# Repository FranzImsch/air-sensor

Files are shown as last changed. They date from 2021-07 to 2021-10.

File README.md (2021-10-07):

# Air Sensor V1.0
A small solar powered ZigBee compatible sensor with energy harvesting for temperature, humidity and VOCs.  
Features nRF52840, AEM10941, SHT40 and SGP40.

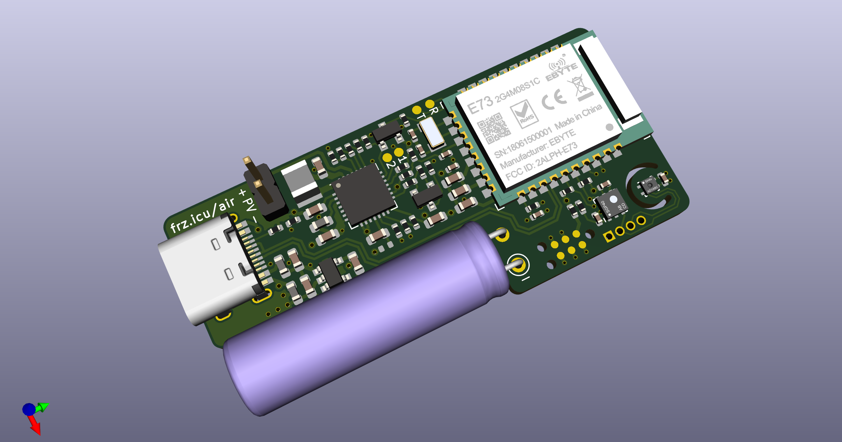
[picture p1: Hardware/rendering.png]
Rendering


## Known Flaws
* Due to the extremely high resistor values of the voltage dividers and their corresponding errors, the set voltage limits are very inaccurate. 
* The overall performance is not completely satisfying, especially indoors pretty much no energy is harvested. (Maybe a different chip like TI's [BQ25570](https://www.ti.com/lit/ds/symlink/bq25570.pdf) could perform better.) The Sensirion sensors perform excellently.

## Software
The proper software (that uses ZigBee) is to be developed. The existing software is a very rudimentary Arduino example to test the sensors. It draws way too much power to be used.

## BOM
The interactive BOM can be found [here](https://franz.science/airsensor-v1.0-ibom/).  

## Reference
e-peas Configuration tool (for the resistors) in the resources section: [Product page](https://e-peas.com/product/aem10941/).

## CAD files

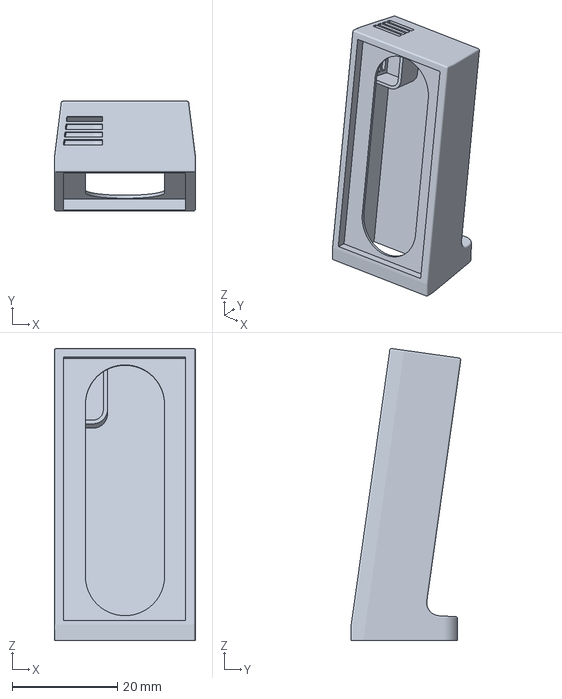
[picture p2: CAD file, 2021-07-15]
Hardware/UMS5_Case.3mf
26.8 x 20.8 x 55.4 mm

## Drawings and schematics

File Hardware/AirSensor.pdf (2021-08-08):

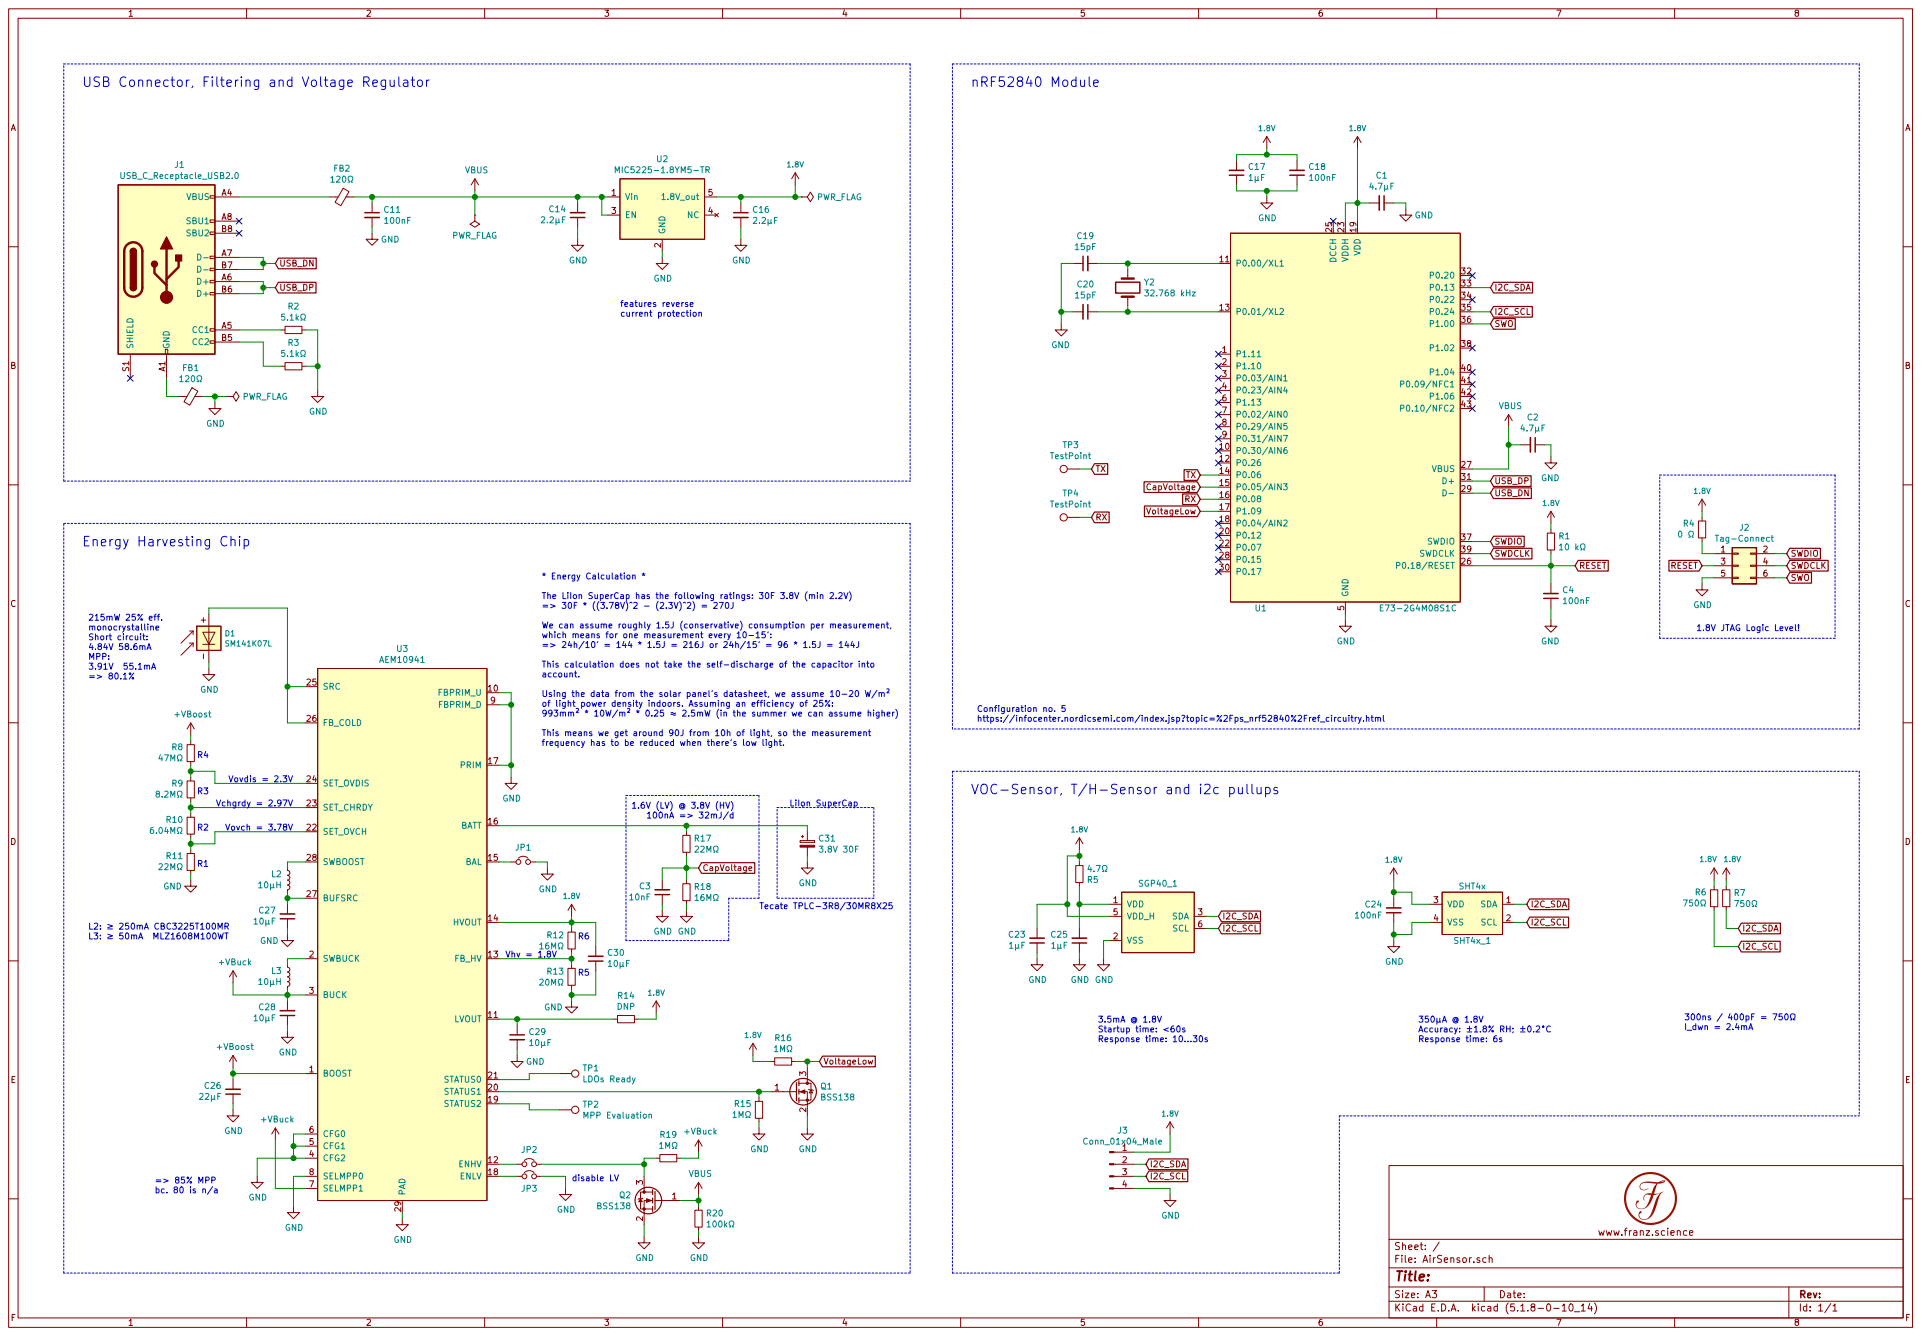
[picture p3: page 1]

The LiIon SuperCap has the following ratings: 30F 3.8V (min 2.2V)

215mW 25% eff. monocrystalline Short circuit: 4.84V 58.6mA MPP: 3.91V 55.1mA

We can assume roughly 1.5J (conservative) consumption per measurement,
which means for one measurement every 10-15: => 24h/10 = 144 * 1.5J = 216J or 24h/15 = 96 * 1.5J = 144J This calculation does not take the self-discharge of the capacitor into

account. Using the data from the solar panels datasheet, we assume 10-20 W/m²

LDOs Ready TP2 MPP Evaluation GND

of light power density indoors. Assuming an efficiency of 25%:
993mm² * 10W/m² * 0.25 2.5mW (in the summer we can assume higher)

https://infocenter.nordicsemi.com/index.jsp?topic=%2Fps_nrf52840%2Fref_circuitry.html

This means we get around 90J from 10h of light, so the measurement

frequency has to be reduced when theres low light. Vovdis = 2.3V

VOC-Sensor, T/H-Sensor and i2c pullups

LiIon SuperCap Tecate TPLC-3R8/30MR8X25

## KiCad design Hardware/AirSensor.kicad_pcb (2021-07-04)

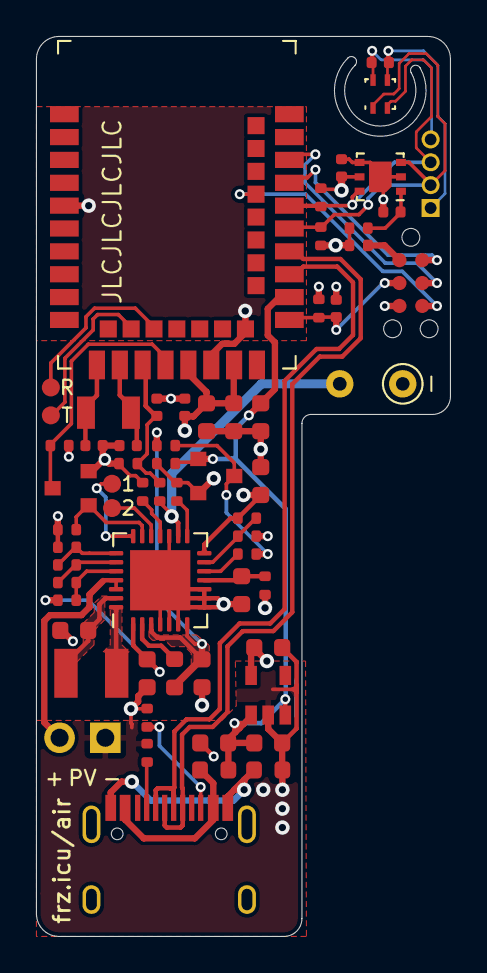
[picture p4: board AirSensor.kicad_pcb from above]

Board: 4 copper layers, 23.0 x 50.0 mm, 63 parts (0 on the bottom side), 42 nets.

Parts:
C1, C2: 4.7µF; C_0603_1608Metric
C3: 10nF; C_0402_1005Metric
C4, C18, C24: 100nF; C_0402_1005Metric
C11: 100nF; C_0603_1608Metric
C14, C16: 2.2µF; C_0603_1608Metric
C17: 1µF; C_0603_1608Metric
C19, C20: 15pF; C_0402_1005Metric
C23, C25: 1µF; C_0402_1005Metric
C26: 22µF; C_0603_1608Metric
C27, C28, C29, C30: 10µF; C_0603_1608Metric
C31: 3.8V 30F; TPLC-3R8_30MR8X25
D1: SM141K07L; PinHeader_1x02_P2.54mm_Vertical
FB1, FB2: 120Ω; L_0603_1608Metric
J1: USB_C_Receptacle_USB2.0; USB_C_Receptacle_HRO_TYPE-C-31-M-12
J2: Tag-Connect; Tag-Connect_TC2030-IDC-NL_2x03_P1.27mm_Vertical
J3: Conn_01x04_Male; PinHeader_1x04_P1.27mm_Vertical
JP1, JP2, JP3: Jumper_NC_Small; R_0402_1005Metric
L2: 10µH; INDC3225X270N
L3: 10µH; L_0603_1608Metric
Q1, Q2: BSS138; SOT-23
R1: 10 kΩ; R_0402_1005Metric
R2, R3: 5.1kΩ; R_0402_1005Metric
R4: 0 Ω; R_0402_1005Metric
R5: 4.7Ω; R_0402_1005Metric
R6, R7: 750Ω; R_0402_1005Metric
R8: 47MΩ; R_0402_1005Metric
R9: 8.2MΩ; R_0402_1005Metric
R10: 6.04MΩ; R_0402_1005Metric
R11, R17: 22MΩ; R_0402_1005Metric
R12, R18: 16MΩ; R_0402_1005Metric
R13: 20MΩ; R_0402_1005Metric
R14: DNP; R_0402_1005Metric
R15, R16, R19: 1MΩ; R_0402_1005Metric
R20: 100kΩ; R_0402_1005Metric
SGP40_1: SGP40
SHT4x_1: SHT4x; Sensirion_SHT4x
TP1: LDOs Ready; TestPoint_Pad_D1.0mm
TP2: MPP Evaluation; TestPoint_Pad_D1.0mm
TP3, TP4: TestPoint; TestPoint_Pad_D1.0mm
U1: E73-2G4M08S1C
U2: MIC5225-1.8YM5-TR; SOT-23-5
U3: AEM10941; QFN-28-1EP_5x5mm_P0.5mm_EP3.35x3.35mm
Y2: 32.768 kHz; Crystal_SMD_3215-2Pin_3.2x1.5mm

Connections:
1.8V: C1.2, C16.1, C17.2, C18.2, C23.2, C24.2, C30.2, J3.1, R1.1, R4.2, R5.1, R6.2, R7.1, R12.1, R14.1, R16.2, SGP40_1.5, SHT4x_1.3, U1.19, U1.23, U2.5, U3.14
+VBoost: C26.2, R8.2, U3.1
+VBuck: C28.2, L3.1, R19.1, U3.3, U3.7
CapVoltage: C3.2, R17.2, R18.1, U1.15
GND: C1.1, C2.1, C3.1, C4.1, C11.2, C14.1, C16.2, C17.1, C18.1, C19.1, C20.2, C23.1, C24.1, C25.1, C26.1, C27.1, C28.1, C29.2, C30.1, C31.-, D1.1, FB1.1, J2.5, J3.4, JP1.2, JP3.2, Q1.2, Q2.2, R2.1, R3.1, R11.1, R13.2, R15.1, R18.2, R20.2, SGP40_1.2, SGP40_1.4, SGP40_1.PAD, SHT4x_1.4, U1.5, U1.21, U1.24, U2.2, U3.4, U3.5, U3.6, U3.8, U3.9, U3.10, U3.17, U3.29
I2C_SCL: J3.3, R6.1, SGP40_1.6, SHT4x_1.2, U1.35
I2C_SDA: J3.2, R7.2, SGP40_1.3, SHT4x_1.1, U1.33
unnamed: C19.2, U1.11, Y2.1
unnamed: C20.1, U1.13, Y2.2
unnamed: C25.2, R5.2, SGP40_1.1
unnamed: C27.2, L2.1, U3.27
unnamed: C29.1, R14.2, U3.11
unnamed: C31.+, R17.1, U3.16
unnamed: D1.2, U3.25, U3.26
unnamed: FB1.2, J1.A1, J1.A12, J1.B1, J1.B12
unnamed: FB2.2, J1.A4, J1.A9, J1.B4, J1.B9
unnamed: J1.A5, R2.2
unnamed: J1.B5, R3.2
unnamed: J2.1, R4.1
unnamed: JP1.1, U3.15
unnamed: JP2.1, U3.12
unnamed: JP2.2, Q2.3, R19.2
unnamed: JP3.1, U3.18
unnamed: L2.2, U3.28
unnamed: L3.2, U3.2
unnamed: Q1.1, R15.2, U3.20
unnamed: R8.1, R9.2, U3.24
unnamed: R10.1, R11.2, U3.22
unnamed: R9.1, R10.2, U3.23
unnamed: R12.2, R13.1, U3.13
unnamed: TP1.1, U3.21
unnamed: TP2.1, U3.19
RESET: C4.2, J2.3, R1.2, U1.26
RX: TP4.1, U1.16
SWDCLK: J2.4, U1.39
SWDIO: J2.2, U1.37
SWO: J2.6, U1.36
TX: TP3.1, U1.14
USB_DN: J1.A7, J1.B7, U1.29
USB_DP: J1.A6, J1.B6, U1.31
VBUS: C2.2, C11.1, C14.2, FB2.1, Q2.1, R20.1, U1.27, U2.1, U2.3
VoltageLow: Q1.3, R16.1, U1.17

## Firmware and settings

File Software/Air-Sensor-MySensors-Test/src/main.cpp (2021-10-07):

#include <Arduino.h>
#include "Adafruit_SHT4x.h"
#include "Adafruit_SGP40.h"

/////// MYSENORS SETTINGS ///////
#define MY_DEBUG
#define MY_RADIO_NRF5_ESB
#define CHILD_ID_TEMP 1
#define CHILD_ID_HUM 2
#define CHILD_ID_IAQ 3
#define SN "air-quality"
#define SV "1.0"
// #define MY_NODE_ID 193

/////// PIN DEFINITIONS ///////
#define CAP_VOLTAGE 16 // P0.05 => D16
#define VOLT_LOW 38    // P1.09 => D38

/////// VOLTAGE MEASUREMENT ///////
#define ADC_FACTOR (0.73242188F)  // 3V / 4096
#define RESISTOR_DIVIDER (678.0F) // this factor has to be determined for every individual device

#include <MySensors.h>

/////// INTERNALS ///////
MyMessage temp_msg(CHILD_ID_TEMP, V_TEMP);
MyMessage hum_msg(CHILD_ID_HUM, V_HUM);
MyMessage iaq_msg(CHILD_ID_IAQ, V_LEVEL);
bool sentInitialValue = false;

bool powerDown = false;

long lastsent = 0;

float lastTemp, lastHum, lastIAQ;

Adafruit_SGP40 sgp;
Adafruit_SHT4x sht4 = Adafruit_SHT4x();

uint32_t i;

void LOW_VOLTAGE_ISR()
{
  powerDown = true;
  Serial.println("----- POWER DOWN!!! -----");
}

void presentation()
{
  sendSketchInfo(SN, SV);
  present(CHILD_ID_TEMP, S_TEMP);
  present(CHILD_ID_HUM, S_HUM);
  present(CHILD_ID_IAQ, S_AIR_QUALITY);
}

void setup()
{

  attachInterrupt(VOLT_LOW, LOW_VOLTAGE_ISR, FALLING);

  // put your setup code here, to run once:
  if (!sht4.begin())
  {
    Serial.println("Couldn't find SHT4x");
    while (1)
      delay(1);
  }
  Serial.println("Found SHT4x sensor");
  Serial.print("Serial number 0x");
  Serial.println(sht4.readSerial(), HEX);
  sht4.setPrecision(SHT4X_MED_PRECISION);
  sht4.setHeater(SHT4X_NO_HEATER);

  if (!sgp.begin())
  {
    Serial.println("SGP40 sensor not found :(");
    while (1)
      ;
  }
  Serial.print("Found SHT3x + SGP40 serial #");
  Serial.print(sgp.serialnumber[0], HEX);
  Serial.print(sgp.serialnumber[1], HEX);
  Serial.println(sgp.serialnumber[2], HEX);
}

void loop()
{
  // For Home Assistant, the first message has to be sent from the loop.
  sensors_event_t humidity, temp;
  sht4.getEvent(&humidity, &temp); // populate temp and humidity objects with fresh data

  if (!sentInitialValue)
  {
    send(temp_msg.set(22, 3)); // send dummy value
    send(hum_msg.set(50, 3));  // send dummy value
    send(iaq_msg.set(100, 0)); // send dummy value
    sendBatteryLevel(50);
    wait(2000);
    sentInitialValue = true;

    for (int n = 0; n <= 230; n++)
    {
      float t = temp.temperature;
      float h = humidity.relative_humidity;
      uint32_t voc_index;
      voc_index = sgp.measureVocIndex(t, h);
      Serial.println(voc_index);
      delay(50);
    }
    Serial.println("finished setup");
  }

  if (!powerDown)
  {
    sensors_event_t humidity, temp;
    sht4.getEvent(&humidity, &temp); // populate temp and humidity objects with fresh data

    float t = temp.temperature;
    float h = humidity.relative_humidity;
    Serial.print("T: ");
    Serial.println(t);
    Serial.print("H: ");
    Serial.println(h);

    uint32_t voc_index;

    voc_index = sgp.measureVocIndex(t, h);
    Serial.print("Voc Index: ");
    Serial.println(voc_index);

    long now = millis();

    if (now >= lastsent + 30000)
    {
      lastsent = now;
      if (t > (lastTemp + 0.5) || t < (lastTemp - 0.5))
      {
        send(temp_msg.set(t, 3));
        lastTemp = t;
      }
      if (h > (lastHum + 3) || h < (lastHum - 3))
      {
        send(hum_msg.set(h, 3));
        lastHum = h;
      }
      if (voc_index > lastIAQ + 2 || voc_index < lastIAQ - 2)
      {
        send(iaq_msg.set(voc_index, 0));
        lastIAQ = voc_index;
      }
    }
  }
  sleep(900000); // 15 Minutes
}

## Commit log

2021-07-04 initialising repo
    [AirSensor.kicad_pcb, AirSensor.sch]
2021-07-15 fixed ibom and added 3d print file
    [AirSensor.kicad_pcb, AirSensor.sch, UMS5_Case.3mf]
2021-08-08 Adding hardware files and 1st readme revision
    [AirSensor.kicad_pcb, AirSensor.sch, UMS5_Case.3mf]
2021-10-07 added rudimentary Arduino test software
